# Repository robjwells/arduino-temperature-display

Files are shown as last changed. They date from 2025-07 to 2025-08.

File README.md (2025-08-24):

## Arduino 7-segment temperature display

This sketch reads the temperature from a TMP36, and displays it on three
7-segment LEDs, via three shift registers.

It uses the `INTERNAL` voltage (about 1.1V) as the analog reference, as the
TMP36 only reaches 1V at about 50°C, and I'm using this as a basic room
thermometer.

The `INTERNAL` voltage on an Atmega 328P isn't exactly 1.1V, so you'll want to
[measure the voltage on your particular chip][measure] and substitute in the
value in millivolts. You could use the default analog reference (5V), but then
you'll only be able to measure in roughly 0.5°C increments.

[measure]: https://forum.arduino.cc/t/measurement-of-bandgap-voltage/38215/4

Here's the circuit in action:

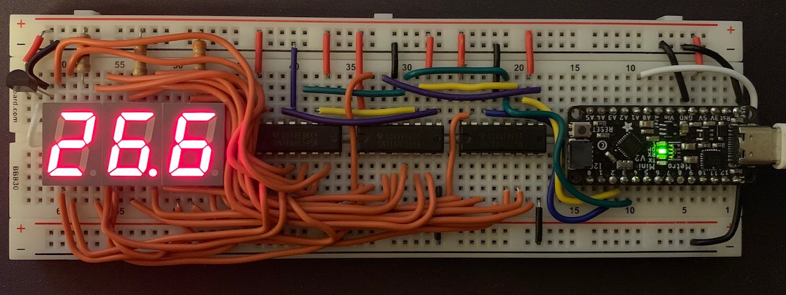
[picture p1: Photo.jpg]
The temperature display circuit built on a breadboard.


And in daylight to make the wiring a bit clearer:

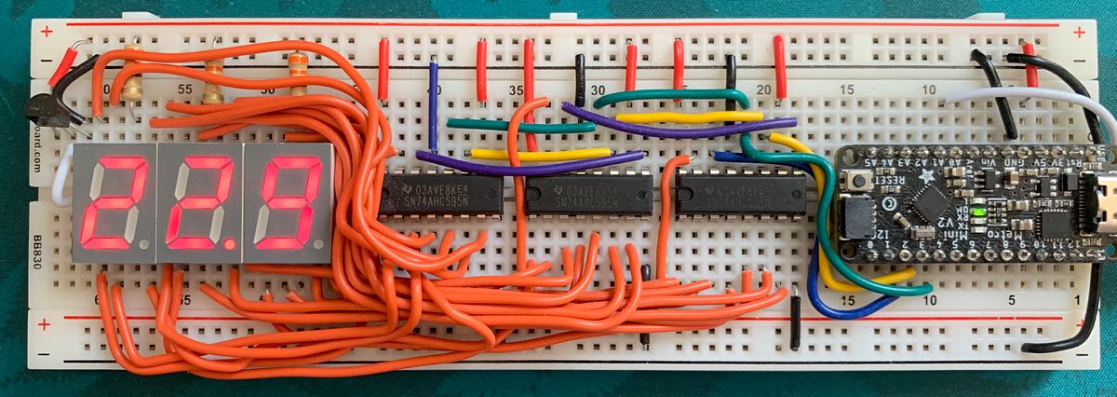
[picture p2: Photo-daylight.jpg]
The circuit in daylight


### Breadboard wiring

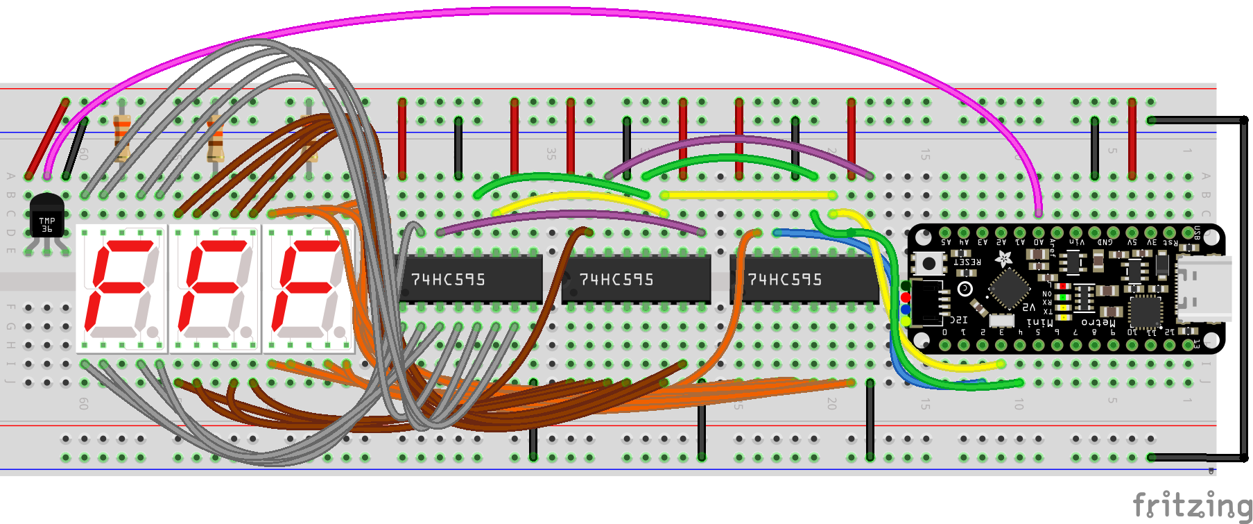
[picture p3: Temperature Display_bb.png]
Fritzing diagram that shows the breadboard wiring


There are a lot of wires! Each 7-segment display takes 8 wires, for 24 wires total.
Each display is wired up in the same way, with Q0 from the shift register wired to
pin 1 (segment E) of the display.

Note that the temperature output wire (in pink) can be run in the central
channel of your breadboard to keep it out of the way (it's the white wire in
the photo above).

### Schematic

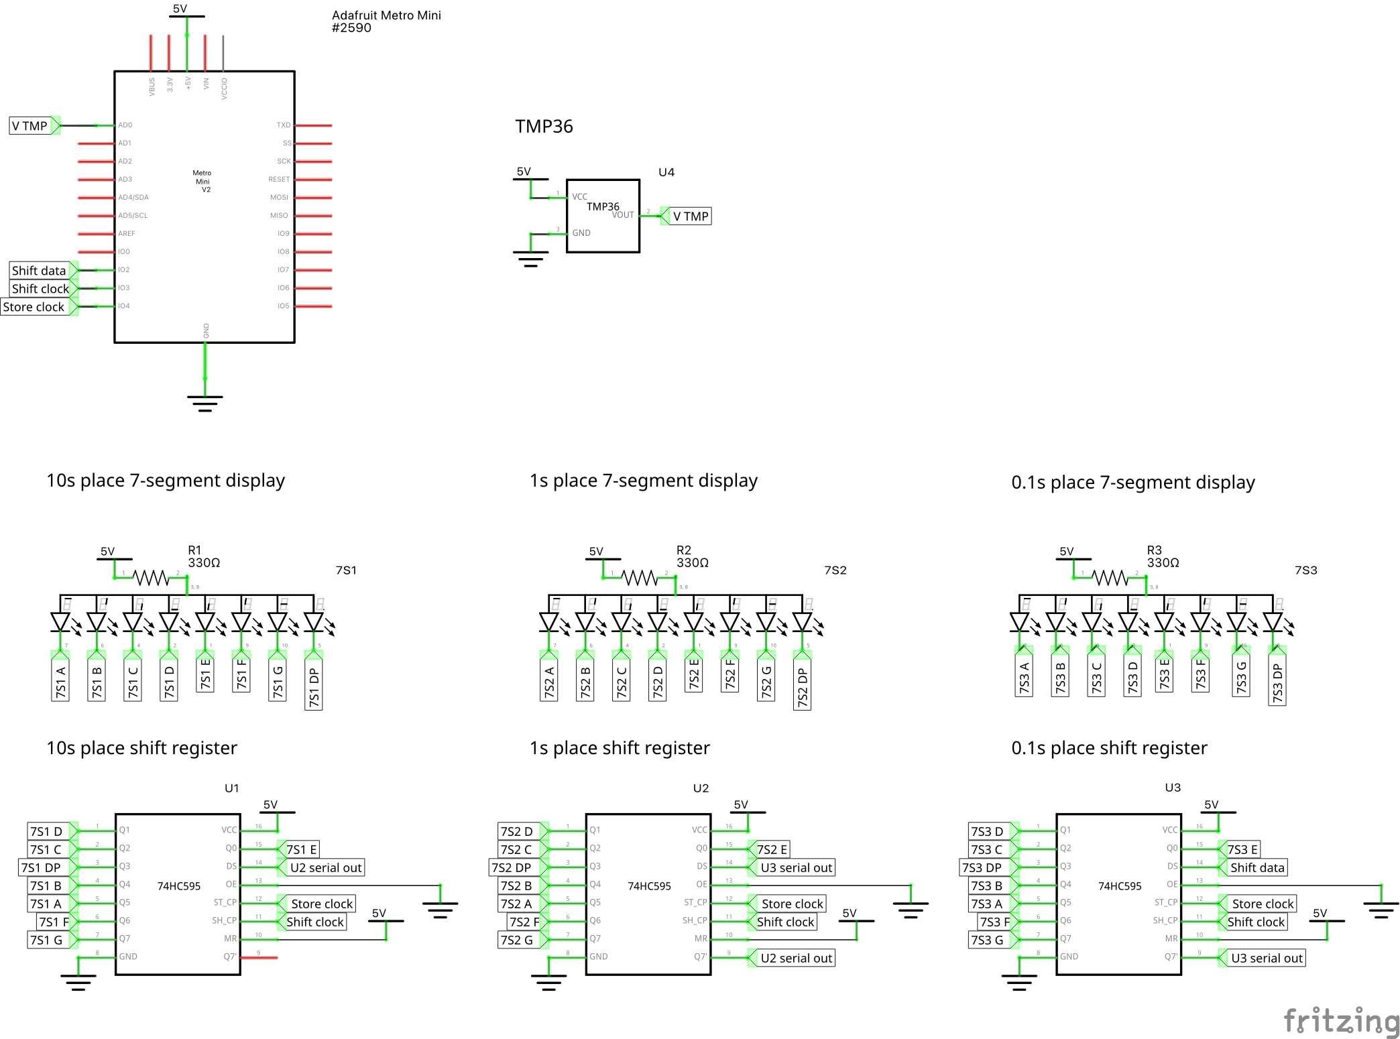
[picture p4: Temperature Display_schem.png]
Circuit schematic


The data is shifted out from the Metro Mini to U3, the tenths-place shift
register (right-most shift register in the breadboard image), which is in turn
chained to U2 (U3 Q7' to U2 data in), which is in turn chained to U1.

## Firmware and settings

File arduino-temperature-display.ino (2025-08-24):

// Pins
#define TEMP_INPUT A0
#define SHIFT_DATA 2
#define SHIFT_CLOCK 3
#define STORE 4

// Update period over which the temperature readings are averaged.
// This helps avoid fluctuations in the displayed temperature.
#define DELAY_SECONDS 60

// Measured voltage (in mV) of the internal analog voltage reference.
// The internal reference is used (rather than the 5V reference) to better
// match the output voltage range of the TMP36 (0.1V to 1.75V).
const float INTERNAL_VOLTAGE_MV = 1053.0;
// Pre-compute the ADC step value.
const float analogStep = INTERNAL_VOLTAGE_MV / 1023.0;

// Active-low bit patterns for decimal numbers on the 7-segment displays.
// Bit order: EDC.BAFG
const byte segments[10] = {
    // 0: ABCDEF
    0b00010001,
    // 1: BC
    0b11010111,
    // 2: ABGED
    0b00110010,
    // 3: ABGCD
    0b10010010,
    // 4: FGBC
    0b11010100,
    // 5: AFGCD
    0b10011000,
    // 6: AFEDCG
    0b00011000,
    // 7: ABC
    0b11010011,
    // 8: ABCDEFG
    0b00010000,
    // 9: ABCDFG
    0b10010000,
};

// Bit pattern to enable the decimal point.
const byte decimalPoint = 0b11101111;

// Pulse the shift registers' store clock to move the shifted-in data to the
// registers' output stage.
void pulseStoreClock() {
    digitalWrite(STORE, HIGH);
    delay(1);
    digitalWrite(STORE, LOW);
}

// Displays a specific pattern on the 7-segment displays until a real
// temperature reading is available.
//
// The shift register contents are unknown on power-up, so this avoids
// weird-looking garbage that makes it look like there's been a fault.
void writeResetPattern() {
    // X-like pattern
    const byte resetSequence[] = {
        // Bit order: EDC.BAFG
        // DA
        0b10111011,
        // G
        0b11111110,
        // DA
        0b10111011,
    };

    for (int idx = 0; idx < 3; idx += 1) {
        shiftOut(SHIFT_DATA, SHIFT_CLOCK, LSBFIRST, resetSequence[idx]);
    }
    pulseStoreClock();
}

// Read temperature from the TMP36.
int readTemperatureInTenthsC() {
    // milliVolt reading from the TMP36
    float mv = analogRead(TEMP_INPUT) * analogStep;
    // Remove the 500mV offset to produce the temperature value in 1/10 °C
    float tenths = mv - 500;
    return (int)tenths;
}

// Intermediate temperature readings (one per second of delay).
int readingBuffer[DELAY_SECONDS];

// Average the readings in readingBuffer.
//
// Returned value is in 10ths of a degree.
int averageOfReadings() {
    int average = 0;
    for (int idx = 0; idx < DELAY_SECONDS; idx += 1) {
        average += readingBuffer[idx];
    }
    return average / DELAY_SECONDS;
}

void setup() {
    analogReference(INTERNAL);      // Internal ~1.1V analog reference.

    pinMode(TEMP_INPUT, INPUT);     // TMP36 analog input (0.1-2.0V).

    pinMode(SHIFT_DATA, OUTPUT);    // 10ths place shift register data input.
    pinMode(SHIFT_CLOCK, OUTPUT);   // Shift registers' clock input.
    pinMode(STORE, OUTPUT);         // Store clock to move data to output stage.
    digitalWrite(STORE, LOW);       // Ensure store clock is low.

    writeResetPattern();            // Initialise the display to a known pattern.
}

void loop() {
    for (int idx = 0; idx < DELAY_SECONDS; idx += 1) {
        readingBuffer[idx] = readTemperatureInTenthsC();
        delay(1000);
    }

    int tenthsC = averageOfReadings();
    byte tensPlace = tenthsC / 100;
    byte onesPlace = tenthsC / 10 % 10;
    byte tenthsPlace = tenthsC % 10;

    // Write out the digits in order left-right.
    shiftOut(SHIFT_DATA, SHIFT_CLOCK, LSBFIRST, segments[tensPlace]);
    shiftOut(SHIFT_DATA, SHIFT_CLOCK, LSBFIRST, segments[onesPlace] & decimalPoint);
    shiftOut(SHIFT_DATA, SHIFT_CLOCK, LSBFIRST, segments[tenthsPlace]);
    // Move data into output stage to display.
    pulseStoreClock();
}

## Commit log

2023-08-13 Use internal 1.1V reference, not 5V
2023-08-13 Average temperature readings over delay period
2025-07-17 Startup pattern, comments, wiring information
    [Temperature Display.fzz]
2025-07-17 Add photo to readme, couple of extra notes
2025-08-24 Fix U3 serial output mislabelled as U1
    [Temperature Display.fzz]
2025-08-24 Fix comment describing reset pattern
    [arduino-temperature-display.ino]
